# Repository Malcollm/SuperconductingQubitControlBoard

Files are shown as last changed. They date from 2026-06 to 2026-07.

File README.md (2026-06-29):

# Superconducting Qubit Control Board

Custom FPGA-based control board for generating microwave I/Q signals used to drive superconducting qubits.

## Project Overview

This project is a hardware and FPGA control system for producing shaped control signals for superconducting qubit experiments. The board uses an FPGA to generate digital waveform data, a high-speed DAC to convert that data into analog I/Q signals, and an RF stage to upconvert the signals to microwave frequencies.

## Main Components

- FPGA digital control and waveform generation
- High-speed DAC for analog I/Q output
- TRF372017 RF modulator / PLL / VCO stage
- SPI control for configurable RF components
- Low-pass filtering between DAC and RF stages
- On-board power regulation and decoupling
- RF output through a controlled-impedance path to SMA

## Design Goals

- Generate programmable I/Q waveforms
- Support microwave signal generation for qubit control
- Keep the design modular and testable
- Document RF layout, DAC interfacing, FPGA control, and signal integrity design

## Current Status

This project is currently in development. The main focus is schematic design, PCB layout, FPGA communication, and validating the signal chain from the FPGA to the RF output.

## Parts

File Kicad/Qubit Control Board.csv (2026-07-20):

Reference | Qty | Value | DNP | Exclude from BOM | Exclude from Board | Footprint | Datasheet
CBULK1,CBULK3,CBULK5,CBULK7,CIN1,CLDO3,CLDO4,CLDO5,CLDO6 | 9 | 10u |  |  |  | Capacitor_SMD:C_1206_3216Metric_Pad1.33x1.80mm_HandSolder
CBULK2,CBULK4,CBULK6,CBULK8 | 4 | 1u |  |  |  | Capacitor_SMD:C_0805_2012Metric_Pad1.18x1.45mm_HandSolder
CC1 | 1 | 47p |  |  |  | Capacitor_SMD:C_0603_1608Metric
CC2 | 1 | 22p |  |  |  | Capacitor_SMD:C_0603_1608Metric
CCDAC1,CCDAC2,CCIN1,CCIP1,CCQN1,CCQP1,CIN2,CRE1 | 8 | 100n |  |  |  | Capacitor_SMD:C_0603_1608Metric
CD1,CD2,CD3,CD4,CD5,CD6,CD7,CD8,CD9,CD10,CD28,CD29,CD30,CD32,CD34,CDC1,CSEN1,CSEN2,CSEN3 | 19 | 100n |  |  |  | Capacitor_SMD:C_0402_1005Metric
CD11,CD20,CD21,CD22,CD26 | 5 | 1u |  |  |  | Capacitor_SMD:C_0603_1608Metric
CD12,CD13,CD18,CD19,CD23,CD24,CD25 | 7 | 4.7p |  |  |  | Capacitor_SMD:C_0402_1005Metric
CD14,CD15,CD16,CD17,CD27 | 5 | 100p |  |  |  | Capacitor_SMD:C_0402_1005Metric
CD31,CD33,CD35,CD36 | 4 | 10n |  |  |  | Capacitor_SMD:C_0402_1005Metric
CIF1,CIF2,CQF1,CQF2 | 4 | 130p |  |  |  | Capacitor_SMD:C_0603_1608Metric
CLDO1,CLDO2 | 2 | 10u |  |  |  | Capacitor_SMD:C_0603_1608Metric
CLDOS1,CLDOS2,CLDOS3 | 3 | 470n |  |  |  | Capacitor_SMD:C_0402_1005Metric
CLF1 | 1 | 270p |  |  |  | Capacitor_SMD:C_0402_1005Metric
CLF2,CLF3 | 2 | 4.7n |  |  |  | Capacitor_SMD:C_0402_1005Metric
F1 | 1 |  |  |  |  | Fuse:Fuse_1206_3216Metric
FB1,FB2,FB3,FB4,FB5,FB6,FB7,FB8 | 8 | 1k @100MHz |  |  |  | Inductor_SMD:L_0603_1608Metric_Pad1.05x0.95mm_HandSolder
J1 | 1 | USB_C_Receptacle_PowerOnly_6P |  |  |  | Connector_USB:USB_C_Receptacle_GCT_USB4135-GF-A_6P_TopMnt_Horizontal | https://www.usb.org/sites/default/files/documents/usb_type-c.zip
J2 | 1 | CLK_Pins |  |  |  | Connector_PinHeader_1.00mm:PinHeader_1x02_P1.00mm_Vertical
J3 | 1 | Idata |  |  |  | Connector_PinHeader_1.00mm:PinHeader_1x11_P1.00mm_Vertical
J4 | 1 | Qdata |  |  |  | Connector_PinHeader_1.00mm:PinHeader_1x11_P1.00mm_Vertical
J5 | 1 | SPIdata |  |  |  | Connector_PinHeader_1.00mm:PinHeader_1x06_P1.00mm_Vertical
J6 | 1 | SMA |  |  |  | Connector_Coaxial:SMA_Molex_73251-1153_EdgeMount_Horizontal
RAP1,RDM1,RDM2,RDM3,RDM4,RDM5,RDM6,RDM7,RDM8 | 9 | 0R |  |  |  | Resistor_SMD:R_0603_1608Metric
RAP2,RAP3 | 2 | DNP |  |  |  | Resistor_SMD:R_0603_1608Metric
Rd1,Rd2 | 2 | 5.1k |  |  |  | Resistor_SMD:R_0603_1608Metric
RDIFF1,RDIFF4 | 2 | 49.9R |  |  |  | Resistor_SMD:R_0603_1608Metric
RDIFF2,RDIFF3 | 2 | 100R |  |  |  | Resistor_SMD:R_0402_1005Metric
RDIV1 | 1 | 1k |  |  |  | Resistor_SMD:R_0603_1608Metric
RDIV2 | 1 | 287R |  |  |  | Resistor_SMD:R_0603_1608Metric
RFS1,RPD1,RPD2,RPD3 | 4 | 10k |  |  |  | Resistor_SMD:R_0603_1608Metric
RID0,RID1,RID2,RID3,RID4,RID5,RID6,RID7,RID8,RID9,RQD0,RQD1,RQD2,RQD3,RQD4,RQD5,RQD6,RQD7,RQD8,RQD9,RT1,RT2,RTSPI1,RTSPI2,RTSPI3,RTSPI4,RTSPI5 | 27 | 33R |  |  |  | Resistor_SMD:R_0402_1005Metric
RINF1,RIPF1,RQNF1,RQPF1 | 4 | 33R |  |  |  | Resistor_SMD:R_0603_1608Metric
RLDOS1,RLDOS2 | 2 | 33.2k |  |  |  | Resistor_SMD:R_0603_1608Metric
RLDOS3 | 1 | 17.8k |  |  |  | Resistor_SMD:R_0603_1608Metric
RLF1,RLF2 | 2 | 1.5k |  |  |  | Resistor_SMD:R_0402_1005Metric
RLOAD1,RLOAD2,RLOAD3,RLOAD4 | 4 | 43.2R |  |  |  | Resistor_SMD:R_0603_1608Metric
U1,U3,U4 | 3 | LT3045xMSE |  |  |  | Package_SO:MSOP-12-1EP_3x4.039mm_P0.65mm_EP1.651x2.845mm | https://www.analog.com/media/en/technical-documentation/data-sheets/3045fa.pdf
U2 | 1 | TRF372017IRGZR |  |  |  | footprints789:RGZ48_5P6X5P6 | https://www.ti.com/lit/gpn/trf372017
U5 | 1 | SN65LVDS1DBV |  |  |  | Package_TO_SOT_SMD:SOT-23-5 | http://www.ti.com/lit/ds/symlink/sn65lvds1.pdf
U6 | 1 | AD9743BCPZ |  |  |  | footprints789:CP-72-1_ADI-M | https://www.analog.com/media/en/technical-documentation/data-sheets/AD9743_9745_9746_9747.pdf
Y2 | 1 | CVHD-950-100.000 |  |  |  | footprints789:OSCSC508P1420X914X530-4N

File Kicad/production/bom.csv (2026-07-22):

Designator | Footprint | Quantity | Value | LCSC Part #
CBULK1, CBULK3, CBULK5, CBULK7, CIN1, CLDO3, CLDO4, CLDO5, CLDO6 | 1206 | 9 | 10u
CBULK2, CBULK4, CBULK6, CBULK8 | 0805 | 4 | 1u
CC1 | 0603 | 1 | 47p
CC2 | 0603 | 1 | 22p
CCDAC1, CCDAC2, CCIN1, CCIP1, CCQN1, CCQP1, CIN2, CRE1 | 0603 | 8 | 100n
CD1, CD10, CD2, CD28, CD29, CD3, CD30, CD32, CD34, CD4, CD5, CD6, CD7, CD8, CD9, CDC1, CSEN1, CSEN2, CSEN3 | 0402 | 19 | 100n
CD11, CD20, CD21, CD22, CD26 | 0603 | 5 | 1u
CD12, CD13, CD18, CD19, CD23, CD24, CD25 | 0402 | 7 | 4.7p
CD14, CD15, CD16, CD17, CD27 | 0402 | 5 | 100p
CD31, CD33, CD35, CD36 | 0402 | 4 | 10n
CIF1, CIF2, CQF1, CQF2 | 0603 | 4 | 130p
CLDO1, CLDO2 | 0603 | 2 | 10u
CLDOS1, CLDOS2, CLDOS3 | 0402 | 3 | 470n
CLF1 | 0402 | 1 | 270p
CLF2, CLF3 | 0402 | 2 | 4.7n
F1 | 1206 | 1 | ~
FB1, FB2, FB3, FB4, FB5, FB6, FB7, FB8 | 0603 | 8 | 1k @100MHz
J1 | USB_C_Receptacle_GCT_USB4135-GF-A_6P_TopMnt_Horizontal | 1 | USB_C_Receptacle_PowerOnly_6P
J2 | PinHeader_1x02_P1.00mm_Vertical | 1 | CLK_Pins
J3 | PinHeader_1x11_P1.00mm_Vertical | 1 | Idata
J4 | PinHeader_1x11_P1.00mm_Vertical | 1 | Qdata
J5 | PinHeader_1x06_P1.00mm_Vertical | 1 | SPIdata
J6 | SMA_Molex_73251-1153_EdgeMount_Horizontal | 1 | SMA
RAP1, RDM1, RDM2, RDM3, RDM4, RDM5, RDM6, RDM7, RDM8 | 0603 | 9 | 0R
RAP2, RAP3 | 0603 | 2 | DNP
RD1, RD2 | 0603 | 2 | 5.1k
RDIFF1, RDIFF4 | 0603 | 2 | 49.9R
RDIFF2, RDIFF3 | 0402 | 2 | 100R
RDIV1 | 0603 | 1 | 1k
RDIV2 | 0603 | 1 | 287R
RFS1, RPD1, RPD2, RPD3 | 0603 | 4 | 10k
RID0, RID1, RID2, RID3, RID4, RID5, RID6, RID7, RID8, RID9, RQD0, RQD1, RQD2, RQD3, RQD4, RQD5, RQD6, RQD7, RQD8, RQD9, RT1, RT2, RTSPI1, RTSPI2, RTSPI3, RTSPI4, RTSPI5 | 0402 | 27 | 33R
RINF1, RIPF1, RQNF1, RQPF1 | 0603 | 4 | 33R
RLDOS1, RLDOS2 | 0603 | 2 | 33.2k
RLDOS3 | 0603 | 1 | 17.8k
RLF1, RLF2 | 0402 | 2 | 1.5k
RLOAD1, RLOAD2, RLOAD3, RLOAD4 | 0603 | 4 | 43.2R
U1, U3, U4 | MSOP-12-1EP_3x4.039mm_P0.65mm_EP1.651x2.845mm | 3 | LT3045xMSE
U2 | RGZ48_5P6X5P6 | 1 | TRF372017IRGZR
U5 | SOT-23-5 | 1 | SN65LVDS1DBV
U6 | CP-72-1_ADI-M | 1 | AD9743BCPZ
Y2 | OSCSC508P1420X914X530-4N | 1 | CVHD-950-100.000

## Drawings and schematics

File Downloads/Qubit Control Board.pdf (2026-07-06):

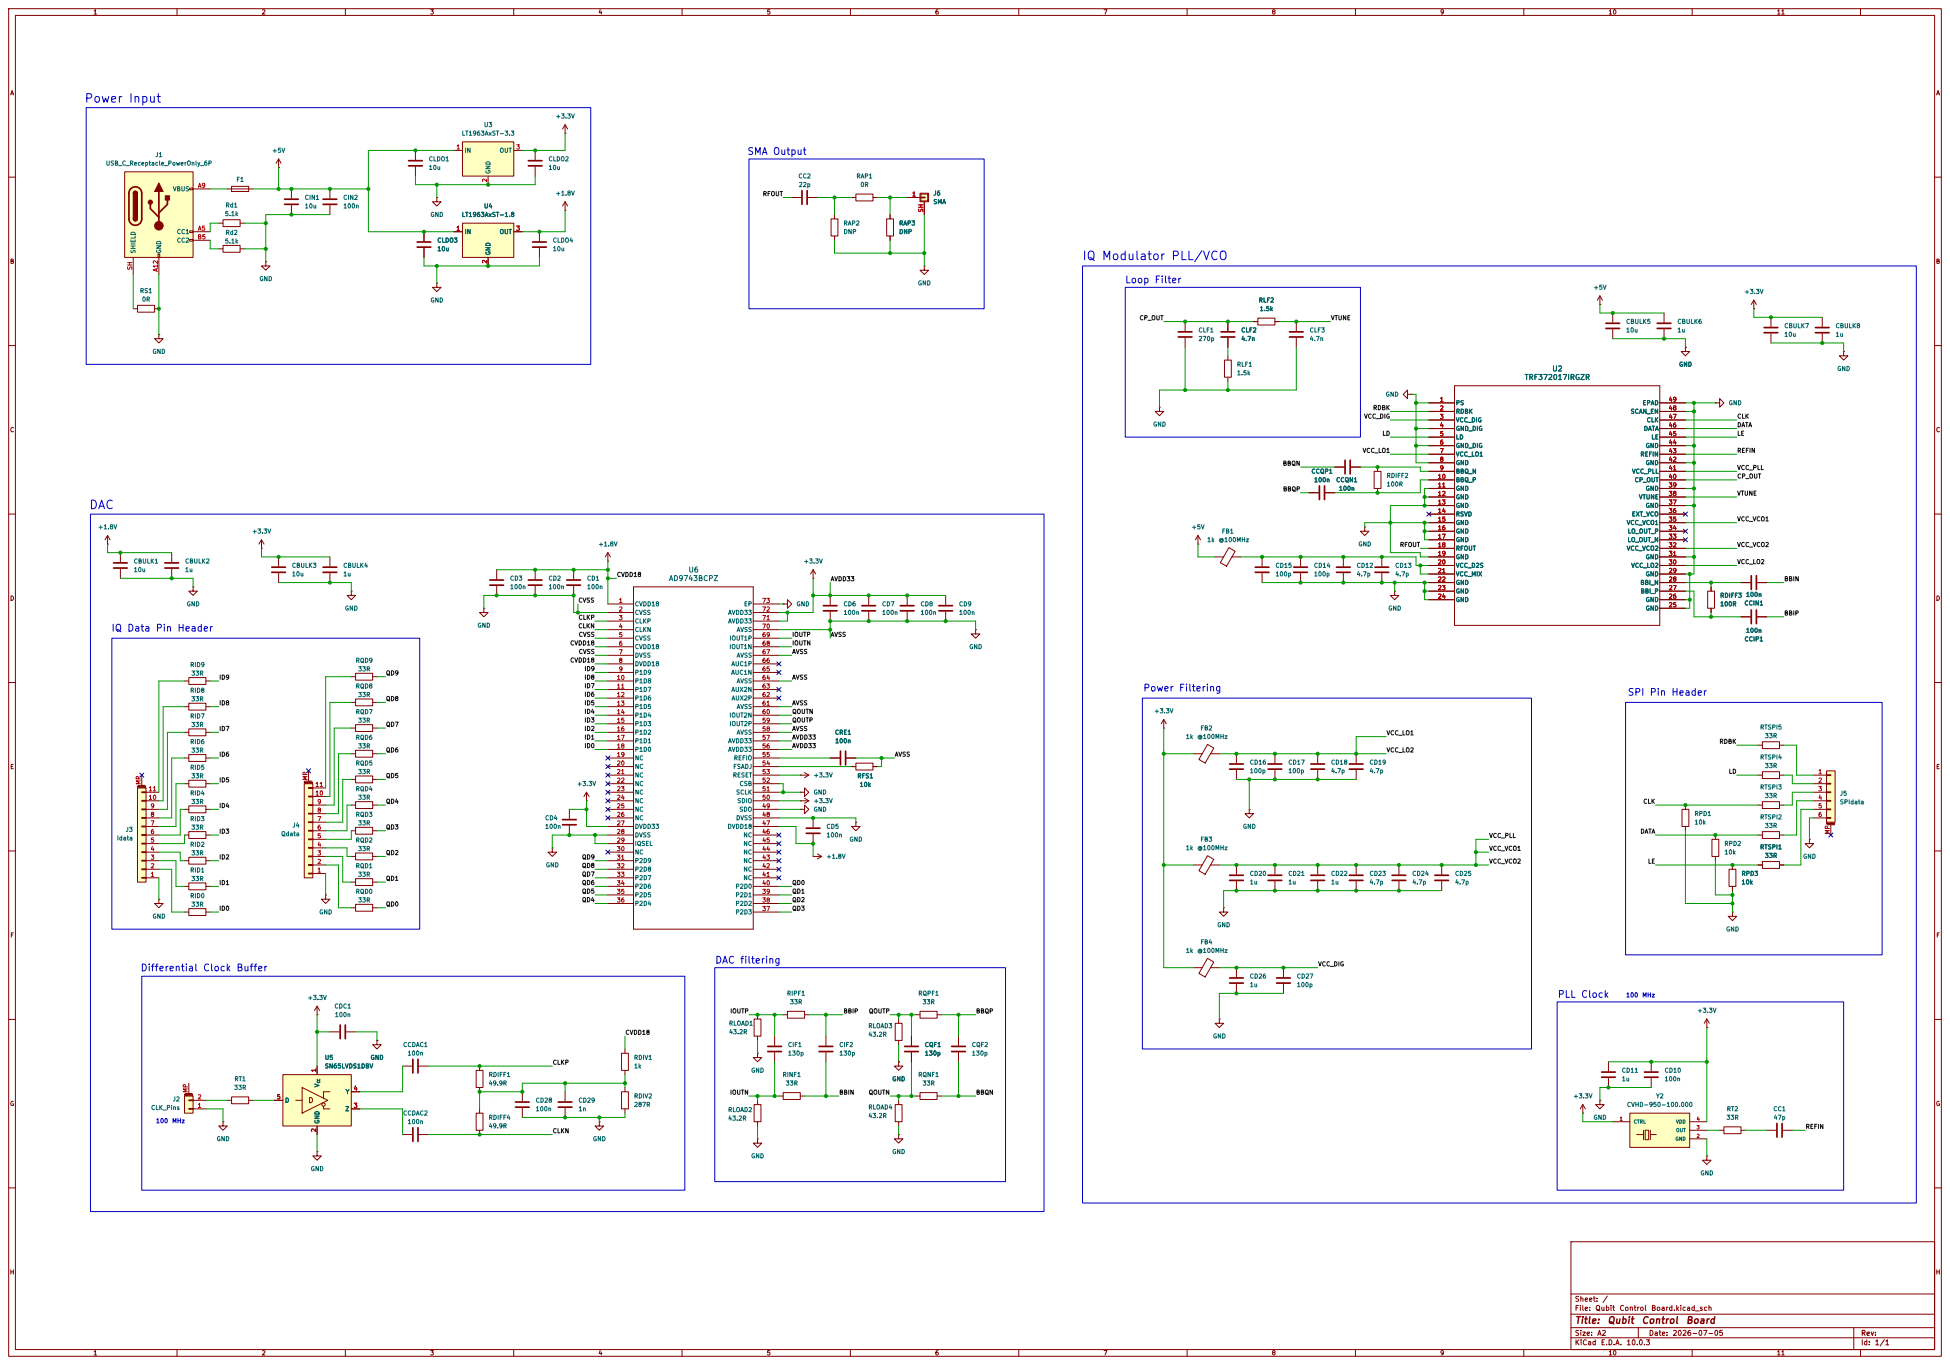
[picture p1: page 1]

IQ Data Pin Header

SPI Pin Header Power Filtering

100 MHz Differential Clock Buffer

Sheet: /
File: Qubit Control Board.kicad_sch
Title: Qubit Control Board

Size: A2 | Rev:
KiCad E.D.A. 10.0.3 | Id: 1/1

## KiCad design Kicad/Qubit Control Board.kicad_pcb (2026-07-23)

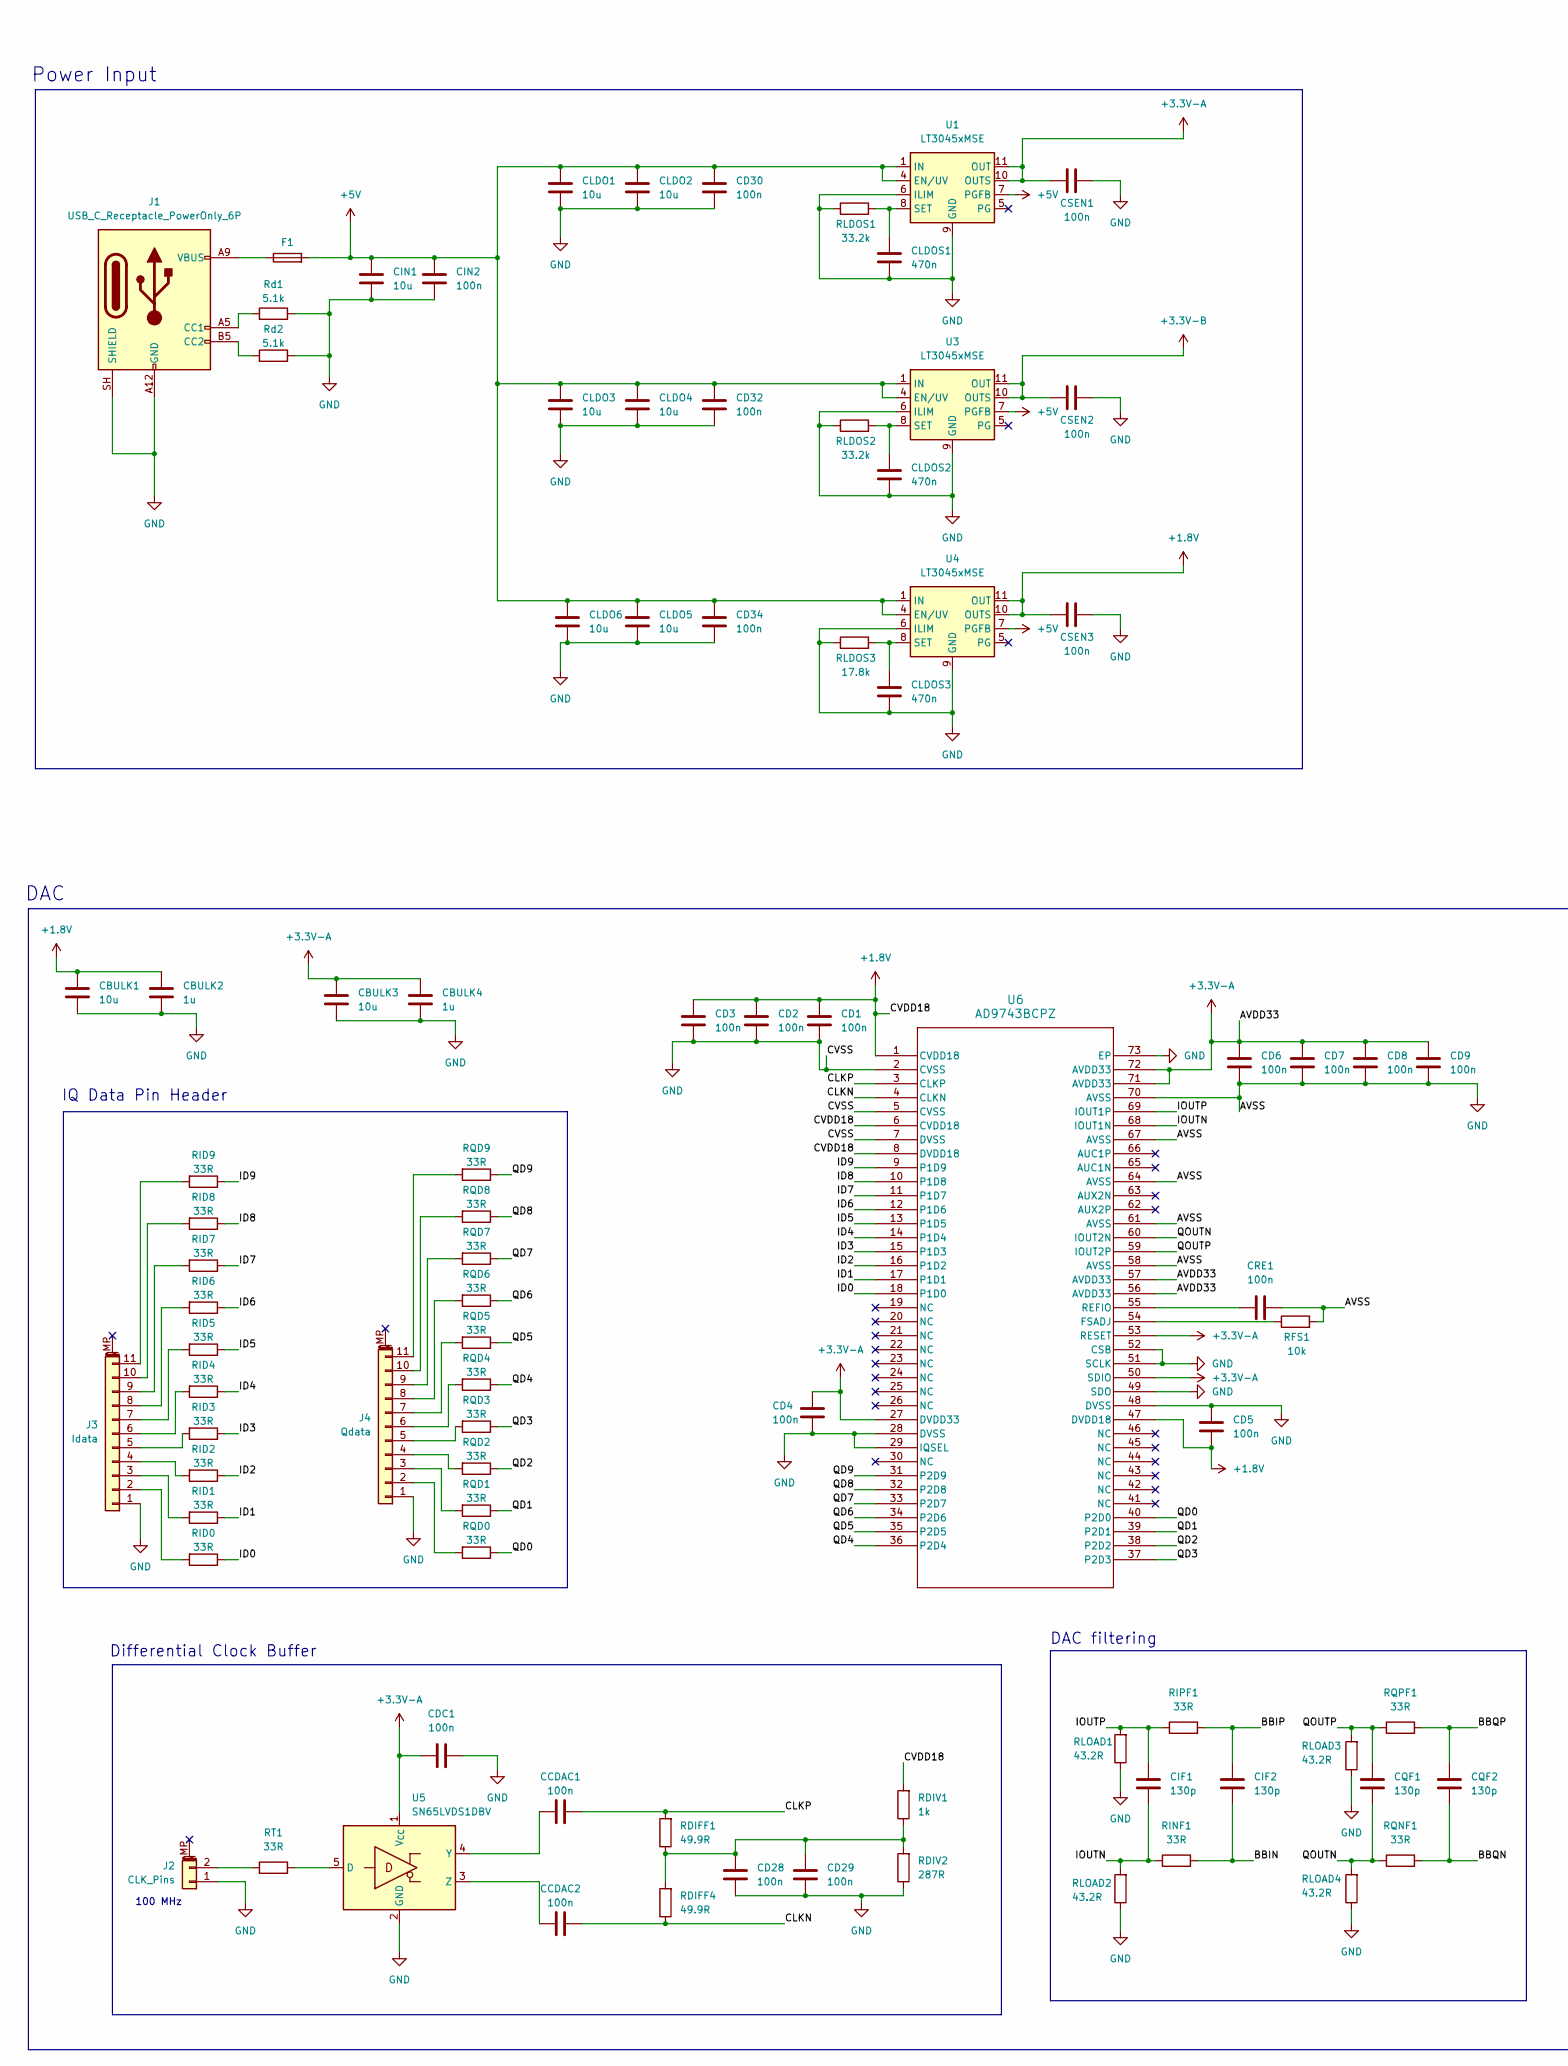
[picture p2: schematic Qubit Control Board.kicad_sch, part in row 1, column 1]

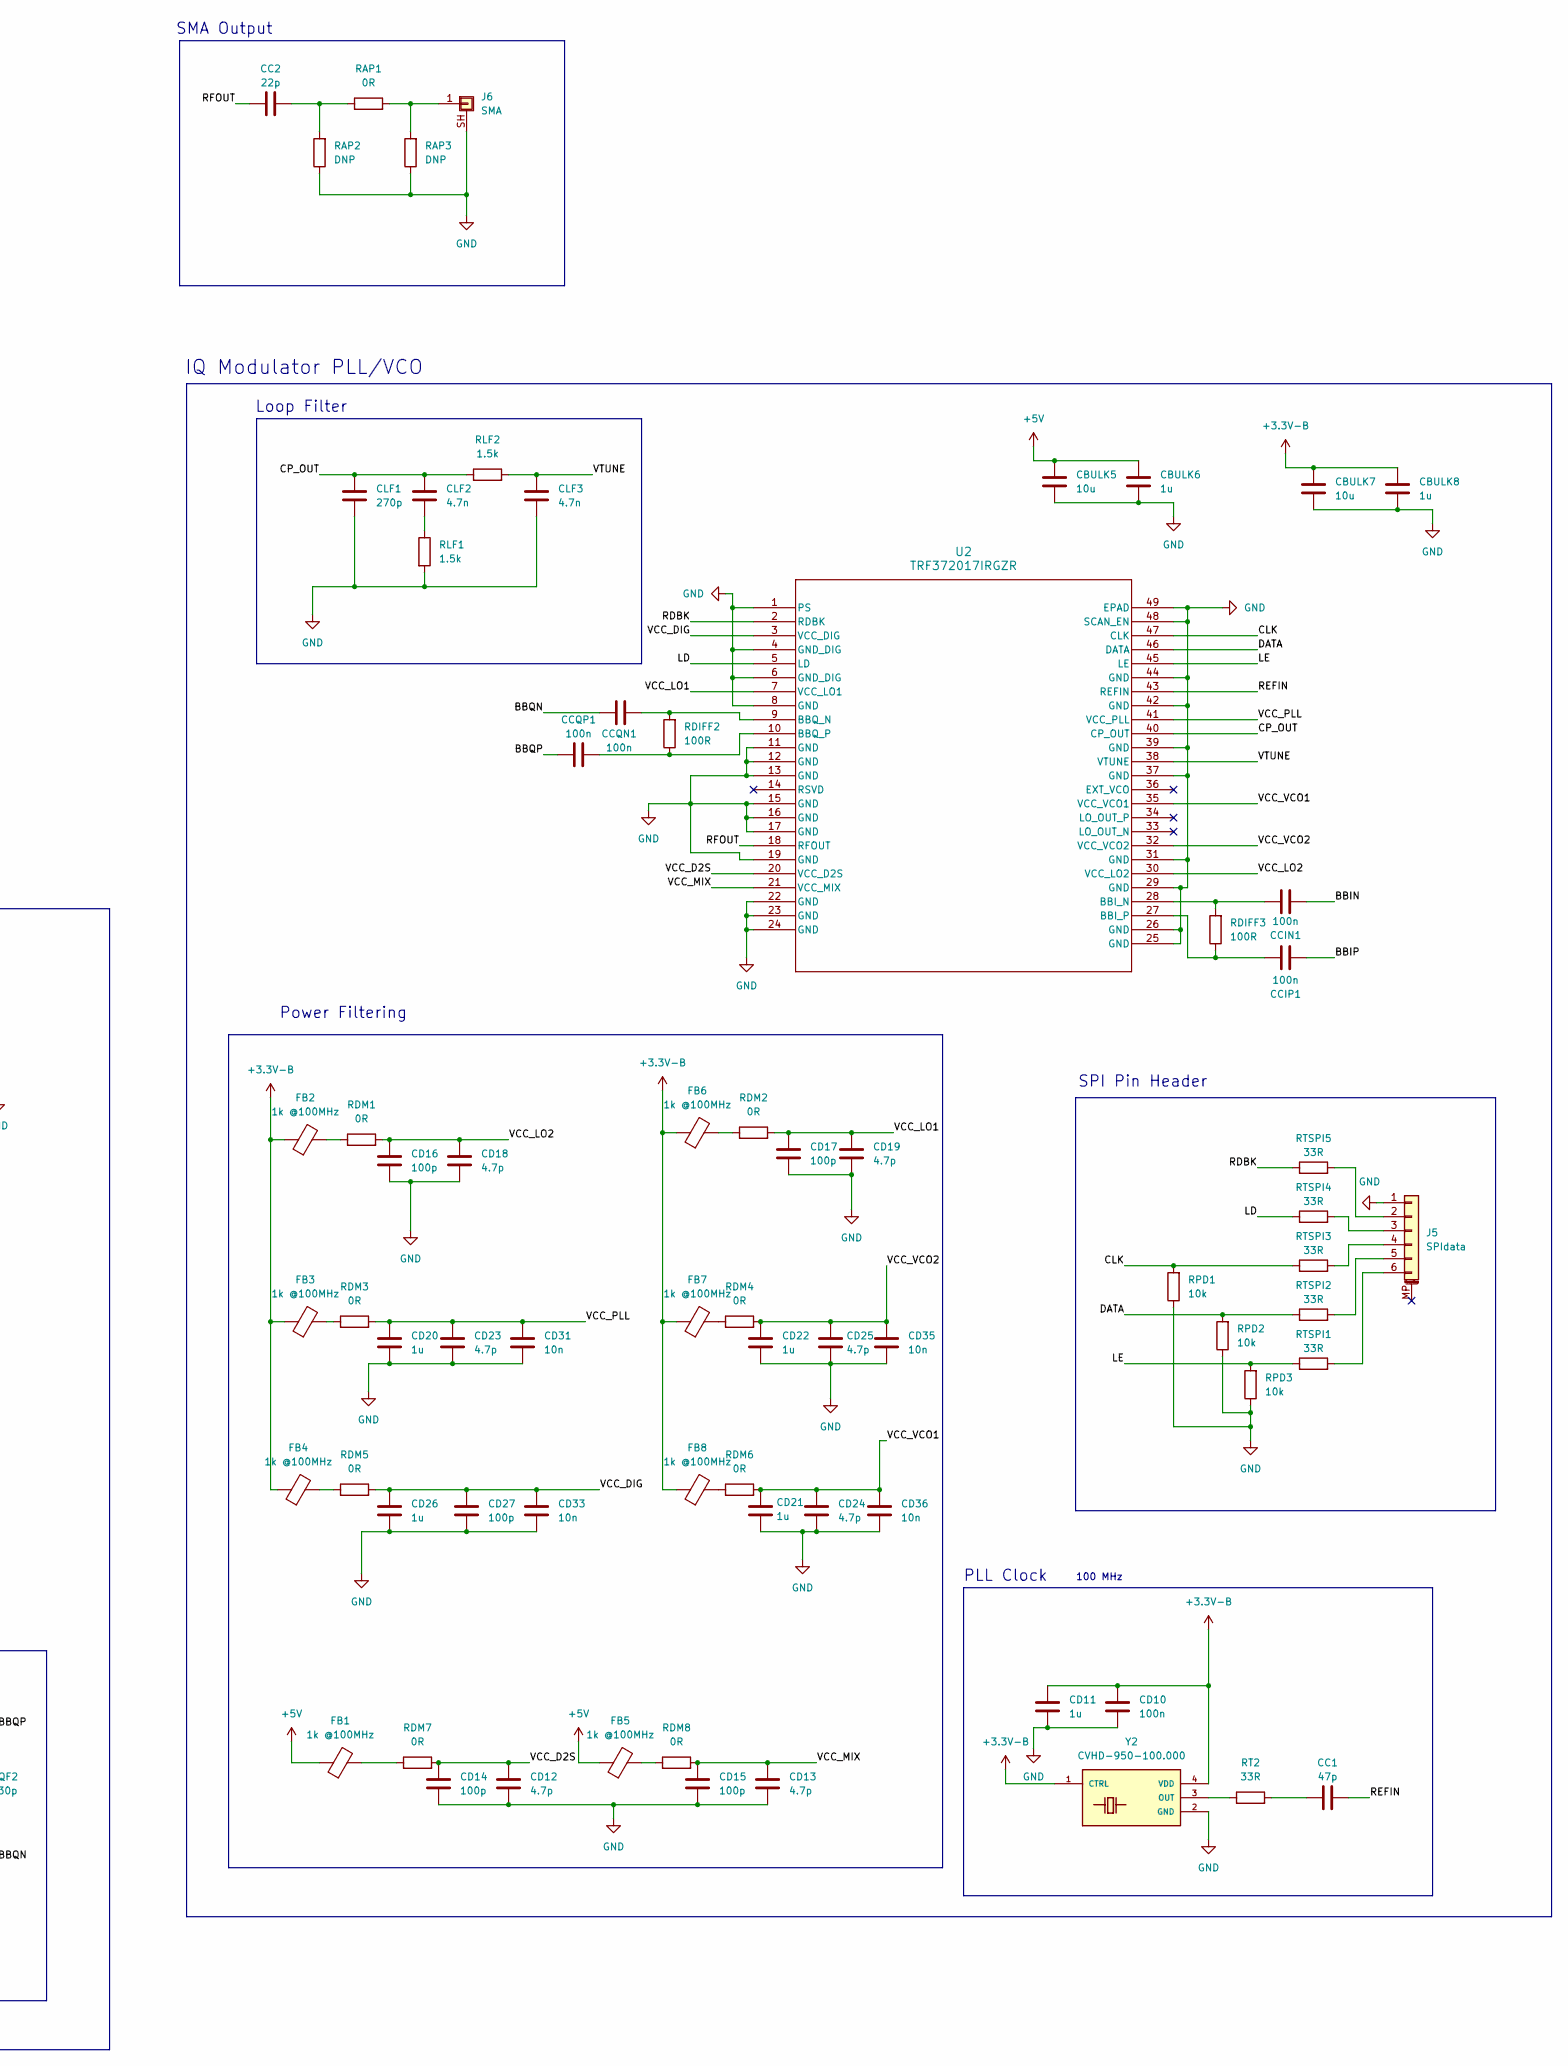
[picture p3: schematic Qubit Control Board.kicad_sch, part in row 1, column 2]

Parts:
CBULK1, CBULK3, CBULK5, CBULK7: 10u; C_1206_3216Metric_Pad1.33x1.80mm_HandSolder
CBULK2, CBULK4, CBULK6, CBULK8: 1u; C_0805_2012Metric_Pad1.18x1.45mm_HandSolder
CC1: 47p; C_0603_1608Metric
CC2: 22p; C_0603_1608Metric
CCDAC1, CCDAC2: 100n; C_0603_1608Metric
CCIN1: 100n; C_0603_1608Metric
CCIP1: 100n; C_0603_1608Metric
CCQN1: 100n; C_0603_1608Metric
CCQP1: 100n; C_0603_1608Metric
CD1, CD2, CD3, CD4, CD5, CD6, CD7, CD8, CD9, CD10, CD28, CD29, CD30, CD32, CD34: 100n; C_0402_1005Metric
CD11, CD20, CD21, CD22, CD26: 1u; C_0603_1608Metric
CD12, CD13, CD18, CD19, CD23, CD24, CD25: 4.7p; C_0402_1005Metric
CD14, CD15, CD16, CD17, CD27: 100p; C_0402_1005Metric
CD31, CD33, CD35, CD36: 10n; C_0402_1005Metric
CDC1: 100n; C_0402_1005Metric
CIF1, CIF2: 130p; C_0603_1608Metric
CIN1: 10u; C_1206_3216Metric_Pad1.33x1.80mm_HandSolder
CIN2: 100n; C_0603_1608Metric
CLDO1, CLDO2: 10u; C_0603_1608Metric
CLDO3, CLDO4, CLDO5, CLDO6: 10u; C_1206_3216Metric_Pad1.33x1.80mm_HandSolder
CLDOS1, CLDOS2, CLDOS3: 470n; C_0402_1005Metric
CLF1: 270p; C_0402_1005Metric
CLF2, CLF3: 4.7n; C_0402_1005Metric
CQF1, CQF2: 130p; C_0603_1608Metric
CRE1: 100n; C_0603_1608Metric
CSEN1, CSEN2, CSEN3: 100n; C_0402_1005Metric
F1: Fuse_1206_3216Metric
FB1, FB2, FB3, FB4, FB5, FB6, FB7, FB8: 1k @100MHz; L_0603_1608Metric_Pad1.05x0.95mm_HandSolder
J1: USB_C_Receptacle_PowerOnly_6P; USB_C_Receptacle_GCT_USB4135-GF-A_6P_TopMnt_Horizontal
J2: CLK_Pins; PinHeader_1x02_P1.00mm_Vertical
J3: Idata; PinHeader_1x11_P1.00mm_Vertical
J4: Qdata; PinHeader_1x11_P1.00mm_Vertical
J5: SPIdata; PinHeader_1x06_P1.00mm_Vertical
J6: SMA; SMA_Molex_73251-1153_EdgeMount_Horizontal
RAP1: 0R; R_0603_1608Metric
RAP2, RAP3: DNP; R_0603_1608Metric
RDIFF1, RDIFF4: 49.9R; R_0603_1608Metric
RDIFF2, RDIFF3: 100R; R_0402_1005Metric
RDIV1: 1k; R_0603_1608Metric
RDIV2: 287R; R_0603_1608Metric
RDM1, RDM2, RDM3, RDM4, RDM5, RDM6, RDM7, RDM8: 0R; R_0603_1608Metric
RFS1: 10k; R_0603_1608Metric
RID0, RID1, RID2, RID3, RID4, RID5, RID6, RID7, RID8, RID9: 33R; R_0402_1005Metric
RINF1: 33R; R_0603_1608Metric
RIPF1: 33R; R_0603_1608Metric
RLDOS1, RLDOS2: 33.2k; R_0603_1608Metric
RLDOS3: 17.8k; R_0603_1608Metric
RLF1, RLF2: 1.5k; R_0402_1005Metric
RLOAD1, RLOAD2, RLOAD3, RLOAD4: 43.2R; R_0603_1608Metric
RPD1, RPD2, RPD3: 10k; R_0603_1608Metric
RQD0, RQD1, RQD2, RQD3, RQD4, RQD5, RQD6, RQD7, RQD8, RQD9: 33R; R_0402_1005Metric
RQNF1: 33R; R_0603_1608Metric
RQPF1: 33R; R_0603_1608Metric
RT1, RT2: 33R; R_0402_1005Metric
RTSPI1, RTSPI2, RTSPI3, RTSPI4, RTSPI5: 33R; R_0402_1005Metric
Rd1, Rd2: 5.1k; R_0603_1608Metric
U1, U3, U4: LT3045xMSE; MSOP-12-1EP_3x4.039mm_P0.65mm_EP1.651x2.845mm
U2: TRF372017IRGZR; RGZ48_5P6X5P6
U5: SN65LVDS1DBV; SOT-23-5
U6: AD9743BCPZ; CP-72-1_ADI-M
Y2: CVHD-950-100.000; OSCSC508P1420X914X530-4N

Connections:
+1.8V: CBULK1.1, CBULK2.1, CD1.2, CD2.2, CD3.2, CD5.1, CSEN3.2, RDIV1.2, U4.10 (OUTS), U4.11 (OUT), U4.12 (OUT), U6.1 (CVDD18), U6.6 (CVDD18), U6.8 (DVDD18), U6.47 (DVDD18)
+3.3V-A: CBULK3.1, CBULK4.1, CD4.2, CD6.2, CD7.2, CD8.2, CD9.2, CDC1.1, CSEN1.2, U1.10 (OUTS), U1.11 (OUT), U1.12 (OUT), U5.1 (V_{CC}), U6.27 (DVDD33), U6.50 (SDIO), U6.53 (RESET), U6.56 (AVDD33), U6.57 (AVDD33), U6.71 (AVDD33), U6.72 (AVDD33)
+3.3V-B: CBULK7.1, CBULK8.1, CD10.2, CD11.2, CSEN2.2, FB2.1, FB3.1, FB4.1, FB6.1, FB7.1, FB8.1, U3.10 (OUTS), U3.11 (OUT), U3.12 (OUT), Y2.1 (CTRL), Y2.4 (VDD)
+5V: CBULK5.1, CBULK6.1, CD30.2, CD32.2, CD34.2, CIN1.1, CIN2.1, CLDO1.1, CLDO2.1, CLDO3.1, CLDO4.1, CLDO5.1, CLDO6.1, F1.2, FB1.1, FB5.1, U1.1 (IN), U1.2 (IN), U1.3 (IN), U1.4 (EN/UV), U1.7 (PGFB), U3.1 (IN), U3.2 (IN), U3.3 (IN), U3.4 (EN/UV), U3.7 (PGFB), U4.1 (IN), U4.2 (IN), U4.3 (IN), U4.4 (EN/UV), U4.7 (PGFB)
/BBIN: CCIN1.1, CIF2.2, RINF1.2
/BBIP: CCIP1.1, CIF2.1, RIPF1.2
/BBQN: CCQN1.1, CQF2.2, RQNF1.2
/BBQP: CCQP1.1, CQF2.1, RQPF1.2
/CLK: RPD1.2, RTSPI3.1, U2.47 (CLK)
/CLKN: CCDAC2.2, RDIFF4.1, U6.4 (CLKN)
/CLKP: CCDAC1.2, RDIFF1.2, U6.3 (CLKP)
/CP_OUT: CLF1.1, CLF2.1, RLF2.1, U2.40 (CP_OUT)
/DATA: RPD2.2, RTSPI2.1, U2.46 (DATA)
/ID0: RID0.1, U6.18 (P1D0)
/ID1: RID1.1, U6.17 (P1D1)
/ID2: RID2.1, U6.16 (P1D2)
/ID3: RID3.1, U6.15 (P1D3)
/ID4: RID4.1, U6.14 (P1D4)
/ID5: RID5.1, U6.13 (P1D5)
/ID6: RID6.1, U6.12 (P1D6)
/ID7: RID7.1, U6.11 (P1D7)
/ID8: RID8.1, U6.10 (P1D8)
/ID9: RID9.1, U6.9 (P1D9)
/IOUTN: CIF1.2, RINF1.1, RLOAD2.2, U6.68 (IOUT1N)
/IOUTP: CIF1.1, RIPF1.1, RLOAD1.2, U6.69 (IOUT1P)
/LD: RTSPI4.1, U2.5 (LD)
/LE: RPD3.2, RTSPI1.1, U2.45 (LE)
/QD0: RQD0.1, U6.40 (P2D0)
/QD1: RQD1.1, U6.39 (P2D1)
/QD2: RQD2.1, U6.38 (P2D2)
/QD3: RQD3.1, U6.37 (P2D3)
/QD4: RQD4.1, U6.36 (P2D4)
/QD5: RQD5.1, U6.35 (P2D5)
/QD6: RQD6.1, U6.34 (P2D6)
/QD7: RQD7.1, U6.33 (P2D7)
/QD8: RQD8.1, U6.32 (P2D8)
/QD9: RQD9.1, U6.31 (P2D9)
/QOUTN: CQF1.2, RLOAD4.2, RQNF1.1, U6.60 (IOUT2N)
/QOUTP: CQF1.1, RLOAD3.2, RQPF1.1, U6.59 (IOUT2P)
/RDBK: RTSPI5.1, U2.2 (RDBK)
/REFIN: CC1.2, U2.43 (REFIN)
/RFOUT: CC2.1, U2.18 (RFOUT)
/VCC_D2S: CD12.2, CD14.2, RDM7.2, U2.20 (VCC_D2S)
/VCC_DIG: CD26.2, CD27.2, CD33.2, RDM5.2, U2.3 (VCC_DIG)
/VCC_LO1: CD17.2, CD19.2, RDM2.2, U2.7 (VCC_LO1)
/VCC_LO2: CD16.2, CD18.2, RDM1.2, U2.30 (VCC_LO2)
/VCC_MIX: CD13.2, CD15.2, RDM8.2, U2.21 (VCC_MIX)
/VCC_PLL: CD20.2, CD23.2, CD31.2, RDM3.2, U2.41 (VCC_PLL)
/VCC_VCO1: CD21.2, CD24.2, CD36.2, RDM6.2, U2.35 (VCC_VCO1)
/VCC_VCO2: CD22.2, CD25.2, CD35.2, RDM4.2, U2.32 (VCC_VCO2)
/VTUNE: CLF3.1, RLF2.2, U2.38 (VTUNE)
GND: CBULK1.2, CBULK2.2, CBULK3.2, CBULK4.2, CBULK5.2, CBULK6.2, CBULK7.2, CBULK8.2, CD1.1, CD2.1, CD3.1, CD4.1, CD5.2, CD6.1, CD7.1, CD8.1, CD9.1, CD10.1, CD11.1, CD12.1, CD13.1, CD14.1, CD15.1, CD16.1, CD17.1, CD18.1, CD19.1, CD20.1, CD21.1, CD22.1, CD23.1, CD24.1, CD25.1, CD26.1, CD27.1, CD28.1, CD29.1, CD30.1, CD31.1, CD32.1, CD33.1, CD34.1, CD35.1, CD36.1, CDC1.2, CIN1.2, CIN2.2, CLDO1.2, CLDO2.2, CLDO3.2, CLDO4.2, CLDO5.2, CLDO6.2, CLDOS1.1, CLDOS2.1, CLDOS3.1, CLF1.2, CLF3.2, CRE1.1, CSEN1.1, CSEN2.1, CSEN3.1, J1.A12 (GND), J1.B12 (GND), J1.SH (SHIELD), J2.1, J3.1, J4.1, J5.1, J6.SH (Shield), RAP2.1, RAP3.1, RDIV2.1, RFS1.2, RLDOS1.1, RLDOS2.1, RLDOS3.1, RLF1.2, RLOAD1.1, RLOAD2.1, RLOAD3.1, RLOAD4.1, RPD1.1, RPD2.1, RPD3.1, Rd1.2, Rd2.2, U1.6 (ILIM), U1.9 (GND), U1.13 (GND), U2.1 (PS), U2.4 (GND_DIG), U2.6 (GND_DIG), U2.8 (GND), U2.11 (GND), U2.12 (GND), U2.13 (GND), U2.15 (GND), U2.16 (GND), U2.17 (GND), U2.19 (GND), U2.22 (GND), U2.23 (GND), U2.24 (GND), U2.25 (GND), U2.26 (GND), U2.29 (GND), U2.31 (GND), U2.37 (GND), U2.39 (GND), U2.42 (GND), U2.44 (GND), U2.48 (SCAN_EN), U2.49 (EPAD), U3.6 (ILIM), U3.9 (GND), U3.13 (GND), U4.6 (ILIM), U4.9 (GND), U4.13 (GND), U5.2 (GND), U6.2 (CVSS), U6.5 (CVSS), U6.7 (DVSS), U6.28 (DVSS), U6.29 (IQSEL), U6.48 (DVSS), U6.49 (SDO), U6.51 (SCLK), U6.52 (CSB), U6.58 (AVSS), U6.61 (AVSS), U6.64 (AVSS), U6.67 (AVSS), U6.70 (AVSS), U6.73 (EP), Y2.2 (GND)
unnamed: CC1.1, RT2.2
unnamed: CC2.2, RAP1.1, RAP2.2
unnamed: CD28.2, CD29.2, RDIFF1.1, RDIFF4.2, RDIV1.1, RDIV2.2
unnamed: CLF2.2, RLF1.1
unnamed: F1.1, J1.A9 (VBUS), J1.B9 (VBUS)
unnamed: FB1.2, RDM7.1
unnamed: FB2.2, RDM1.1
unnamed: FB3.2, RDM3.1
unnamed: FB4.2, RDM5.1
unnamed: FB5.2, RDM8.1
unnamed: FB6.2, RDM2.1
unnamed: FB7.2, RDM4.1
unnamed: FB8.2, RDM6.1
unnamed: J1.A5 (CC1), Rd1.1
unnamed: J1.B5 (CC2), Rd2.1
unnamed: J2.2, RT1.1
unnamed: J3.2, RID0.2
unnamed: J3.3, RID1.2
unnamed: J3.4, RID2.2
unnamed: J3.5, RID3.2
unnamed: J3.6, RID4.2
unnamed: J3.7, RID5.2
unnamed: J3.8, RID6.2
unnamed: J3.9, RID7.2
unnamed: J3.10, RID8.2
unnamed: J3.11, RID9.2
unnamed: J4.2, RQD0.2
unnamed: J4.3, RQD1.2
unnamed: J4.4, RQD2.2
unnamed: J4.5, RQD3.2
unnamed: J4.6, RQD4.2
unnamed: J4.7, RQD5.2
unnamed: J4.8, RQD6.2
unnamed: J4.9, RQD7.2
unnamed: J4.10, RQD8.2
unnamed: J4.11, RQD9.2
unnamed: J5.2, RTSPI5.2
unnamed: J5.3, RTSPI4.2
unnamed: J5.4, RTSPI3.2
unnamed: J5.5, RTSPI2.2
unnamed: J5.6, RTSPI1.2
unnamed: J6.1 (Pin_1_1), RAP1.2, RAP3.2
unnamed: CLDOS1.2, RLDOS1.2, U1.8 (SET)
unnamed: CCIN1.2, RDIFF3.2, U2.28 (BBI_N)
unnamed: CCIP1.2, RDIFF3.1, U2.27 (BBI_P)
unnamed: CCQN1.2, RDIFF2.2, U2.9 (BBQ_N)
unnamed: CCQP1.2, RDIFF2.1, U2.10 (BBQ_P)
unnamed: CLDOS2.2, RLDOS2.2, U3.8 (SET)
unnamed: CLDOS3.2, RLDOS3.2, U4.8 (SET)
unnamed: RT1.2, U5.5 (D)
unnamed: CCDAC1.1, U5.4 (Y)
unnamed: CCDAC2.1, U5.3 (Z)
unnamed: RFS1.1, U6.54 (FSADJ)
unnamed: CRE1.2, U6.55 (REFIO)
unnamed: RT2.1, Y2.3 (OUT)

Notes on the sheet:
SMA Output
100 MHz
SPI Pin Header
Power Filtering
DAC filtering
Loop Filter
IQ Data Pin Header
DAC
IQ Modulator PLL/VCO
Differential Clock Buffer
Power Input
PLL Clock

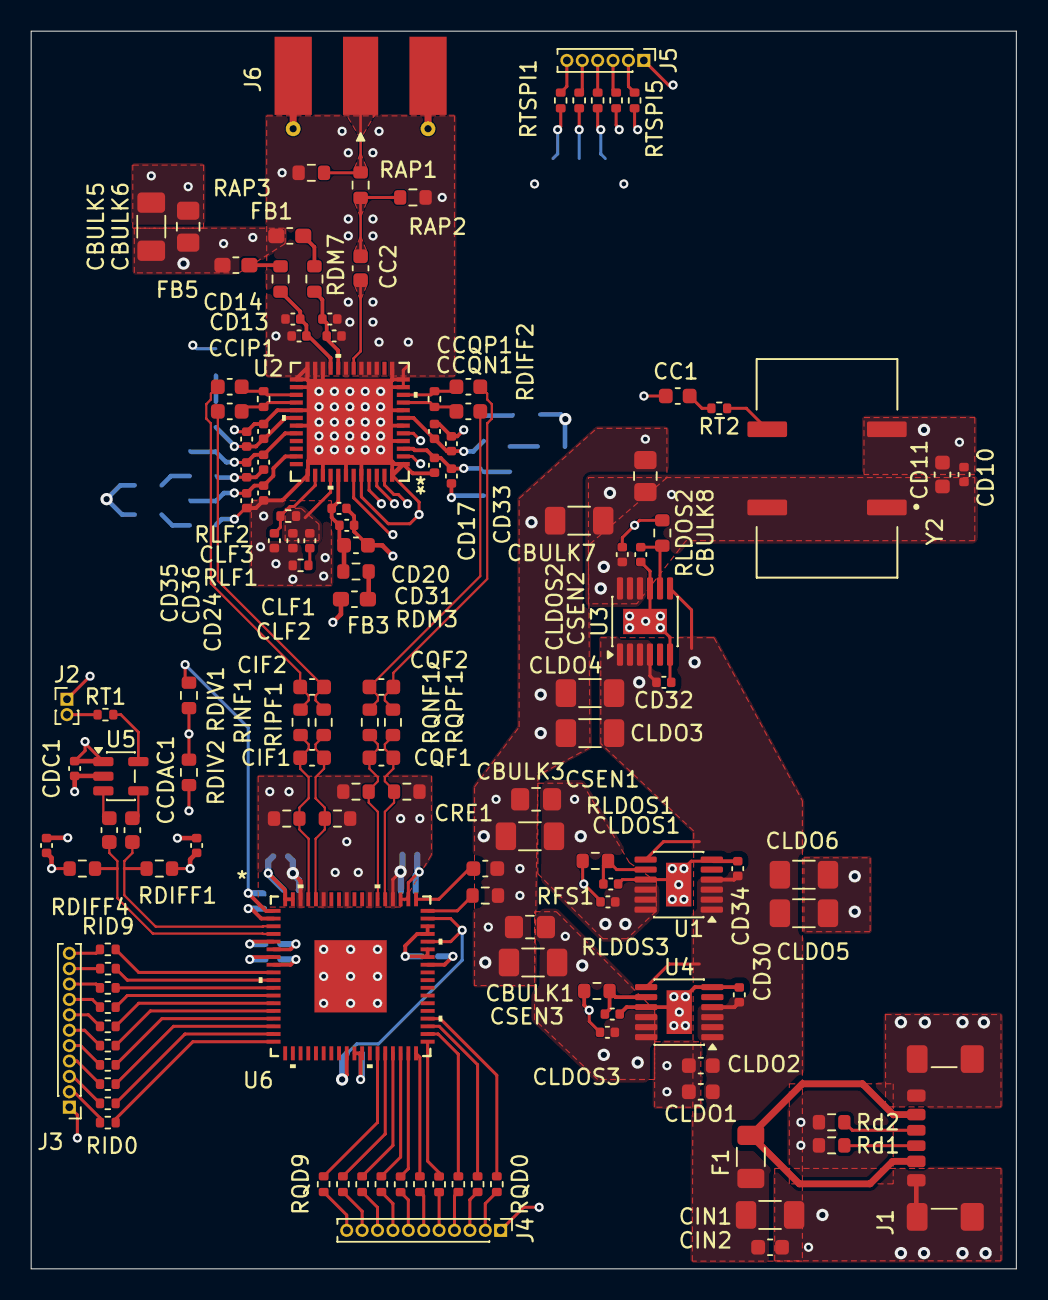
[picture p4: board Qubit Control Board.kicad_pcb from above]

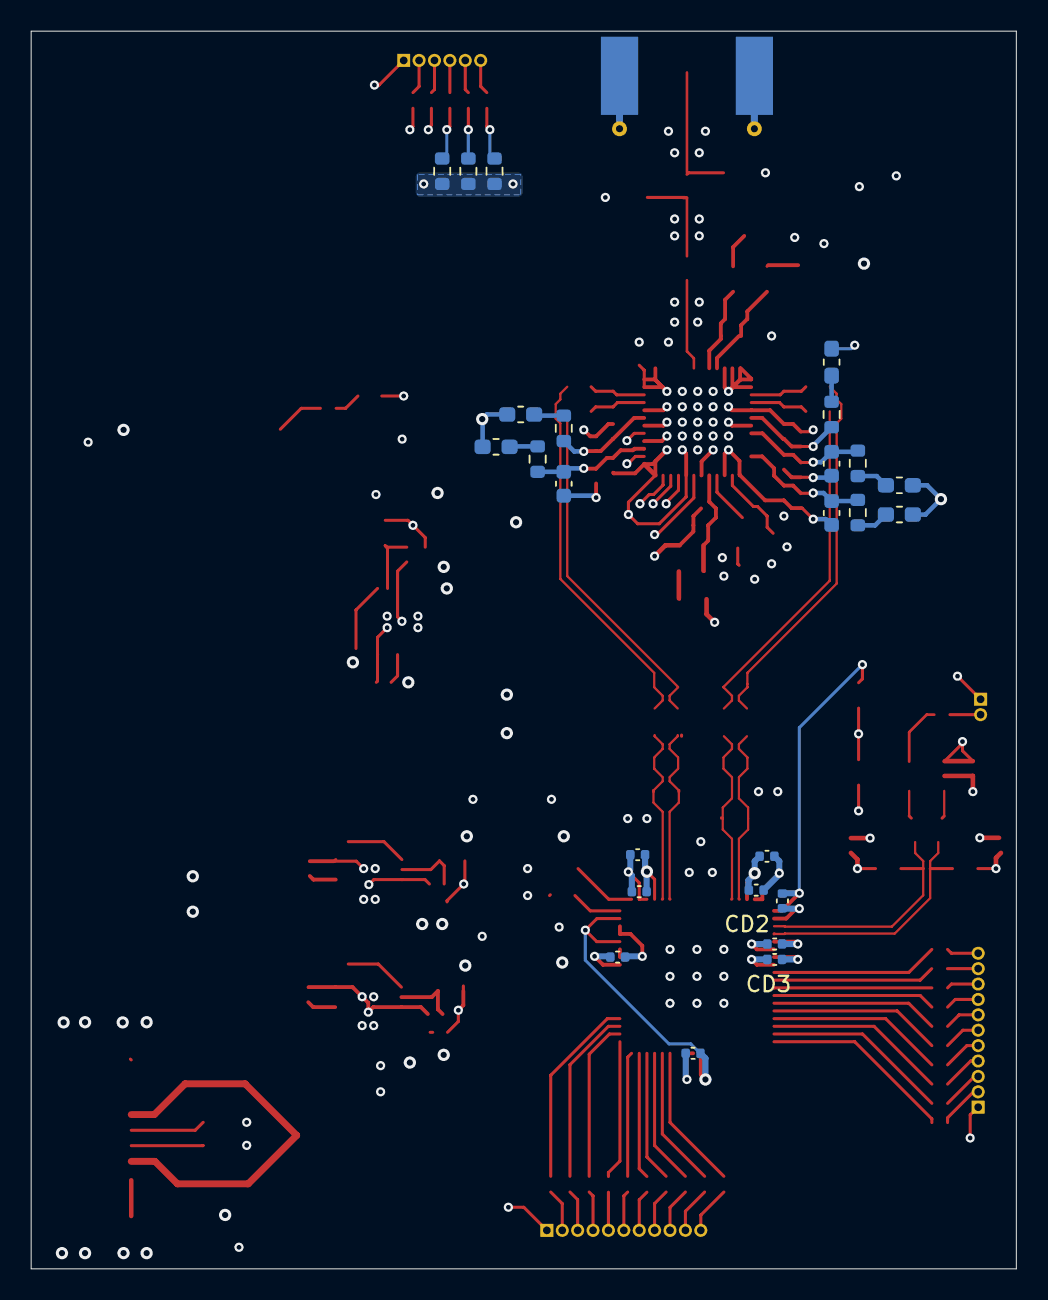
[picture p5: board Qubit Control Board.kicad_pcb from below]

Board: 6 copper layers, 64.0 x 80.4 mm, 160 parts (25 on the bottom side), 107 nets.

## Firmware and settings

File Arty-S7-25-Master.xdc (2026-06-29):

## This file is a general .xdc for the Arty S7-25 Rev. E
## To use it in a project:
## - uncomment the lines corresponding to used pins
## - rename the used ports (in each line, after get_ports) according to the top level signal names in the project

## Clock Signals
#set_property -dict { PACKAGE_PIN F14   IOSTANDARD LVCMOS33 } [get_ports { CLK12MHZ }]; #IO_L13P_T2_MRCC_15 Sch=uclk
#create_clock -add -name sys_clk_pin -period 83.333 -waveform {0 41.667} [get_ports { CLK12MHZ }];
set_property -dict { PACKAGE_PIN R2    IOSTANDARD SSTL135 } [get_ports { CLK100MHZ }]; #IO_L12P_T1_MRCC_34 Sch=ddr3_clk[200]
create_clock -add -name sys_clk_pin -period 10.000 -waveform {0 5.000}  [get_ports { CLK100MHZ }];

## Switches
#set_property -dict { PACKAGE_PIN H14   IOSTANDARD LVCMOS33 } [get_ports { sw[0] }]; #IO_L20N_T3_A19_15 Sch=sw[0]
#set_property -dict { PACKAGE_PIN H18   IOSTANDARD LVCMOS33 } [get_ports { sw[1] }]; #IO_L21P_T3_DQS_15 Sch=sw[1]
#set_property -dict { PACKAGE_PIN G18   IOSTANDARD LVCMOS33 } [get_ports { sw[2] }]; #IO_L21N_T3_DQS_A18_15 Sch=sw[2]
#set_property -dict { PACKAGE_PIN M5    IOSTANDARD SSTL135 } [get_ports { sw[3] }]; #IO_L6N_T0_VREF_34 Sch=sw[3]

## RGB LEDs
#set_property -dict { PACKAGE_PIN J15   IOSTANDARD LVCMOS33 } [get_ports { led0_r }]; #IO_L23N_T3_FWE_B_15 Sch=led0_r
#set_property -dict { PACKAGE_PIN G17   IOSTANDARD LVCMOS33 } [get_ports { led0_g }]; #IO_L14N_T2_SRCC_15 Sch=led0_g
#set_property -dict { PACKAGE_PIN F15   IOSTANDARD LVCMOS33 } [get_ports { led0_b }]; #IO_L13N_T2_MRCC_15 Sch=led0_b
#set_property -dict { PACKAGE_PIN E15   IOSTANDARD LVCMOS33 } [get_ports { led1_r }]; #IO_L15N_T2_DQS_ADV_B_15 Sch=led1_r
#set_property -dict { PACKAGE_PIN F18   IOSTANDARD LVCMOS33 } [get_ports { led1_g }]; #IO_L16P_T2_A28_15 Sch=led1_g
#set_property -dict { PACKAGE_PIN E14   IOSTANDARD LVCMOS33 } [get_ports { led1_b }]; #IO_L15P_T2_DQS_15 Sch=led1_b

## LEDs
set_property -dict { PACKAGE_PIN E18   IOSTANDARD LVCMOS33 } [get_ports { led[0] }]; #IO_L16N_T2_A27_15 Sch=led[2]
set_property -dict { PACKAGE_PIN F13   IOSTANDARD LVCMOS33 } [get_ports { led[1] }]; #IO_L17P_T2_A26_15 Sch=led[3]
set_property -dict { PACKAGE_PIN E13   IOSTANDARD LVCMOS33 } [get_ports { led[2] }]; #IO_L17N_T2_A25_15 Sch=led[4]
set_property -dict { PACKAGE_PIN H15   IOSTANDARD LVCMOS33 } [get_ports { led[3] }]; #IO_L18P_T2_A24_15 Sch=led[5]

## Buttons
#set_property -dict { PACKAGE_PIN G15   IOSTANDARD LVCMOS33 } [get_ports { btn[0] }]; #IO_L18N_T2_A23_15 Sch=btn[0]
#set_property -dict { PACKAGE_PIN K16   IOSTANDARD LVCMOS33 } [get_ports { btn[1] }]; #IO_L19P_T3_A22_15 Sch=btn[1]
#set_property -dict { PACKAGE_PIN J16   IOSTANDARD LVCMOS33 } [get_ports { btn[2] }]; #IO_L19N_T3_A21_VREF_15 Sch=btn[2]
#set_property -dict { PACKAGE_PIN H13   IOSTANDARD LVCMOS33 } [get_ports { btn[3] }]; #IO_L20P_T3_A20_15 Sch=btn[3]

## Pmod Header JA
#set_property -dict { PACKAGE_PIN L17   IOSTANDARD LVCMOS33 } [get_ports { ja[0] }]; #IO_L4P_T0_D04_14 Sch=ja_p[1]
#set_property -dict { PACKAGE_PIN L18   IOSTANDARD LVCMOS33 } [get_ports { ja[1] }]; #IO_L4N_T0_D05_14 Sch=ja_n[1]
#set_property -dict { PACKAGE_PIN M14   IOSTANDARD LVCMOS33 } [get_ports { ja[2] }]; #IO_L5P_T0_D06_14 Sch=ja_p[2]
#set_property -dict { PACKAGE_PIN N14   IOSTANDARD LVCMOS33 } [get_ports { ja[3] }]; #IO_L5N_T0_D07_14 Sch=ja_n[2]
#set_property -dict { PACKAGE_PIN M16   IOSTANDARD LVCMOS33 } [get_ports { ja[4] }]; #IO_L7P_T1_D09_14 Sch=ja_p[3]
#set_property -dict { PACKAGE_PIN M17   IOSTANDARD LVCMOS33 } [get_ports { ja[5] }]; #IO_L7N_T1_D10_14 Sch=ja_n[3]
#set_property -dict { PACKAGE_PIN M18   IOSTANDARD LVCMOS33 } [get_ports { ja[6] }]; #IO_L8P_T1_D11_14 Sch=ja_p[4]
#set_property -dict { PACKAGE_PIN N18   IOSTANDARD LVCMOS33 } [get_ports { ja[7] }]; #IO_L8N_T1_D12_14 Sch=ja_n[4]

## Pmod Header JB
#set_property -dict { PACKAGE_PIN P17   IOSTANDARD LVCMOS33 } [get_ports { jb[0] }]; #IO_L9P_T1_DQS_14 Sch=jb_p[1]
#set_property -dict { PACKAGE_PIN P18   IOSTANDARD LVCMOS33 } [get_ports { jb[1] }]; #IO_L9N_T1_DQS_D13_14 Sch=jb_n[1]
#set_property -dict { PACKAGE_PIN R18   IOSTANDARD LVCMOS33 } [get_ports { jb[2] }]; #IO_L10P_T1_D14_14 Sch=jb_p[2]
#set_property -dict { PACKAGE_PIN T18   IOSTANDARD LVCMOS33 } [get_ports { jb[3] }]; #IO_L10N_T1_D15_14 Sch=jb_n[2]
#set_property -dict { PACKAGE_PIN P14   IOSTANDARD LVCMOS33 } [get_ports { jb[4] }]; #IO_L11P_T1_SRCC_14 Sch=jb_p[3]
#set_property -dict { PACKAGE_PIN P15   IOSTANDARD LVCMOS33 } [get_ports { jb[5] }]; #IO_L11N_T1_SRCC_14 Sch=jb_n[3]
#set_property -dict { PACKAGE_PIN N15   IOSTANDARD LVCMOS33 } [get_ports { jb[6] }]; #IO_L12P_T1_MRCC_14 Sch=jb_p[4]
#set_property -dict { PACKAGE_PIN P16   IOSTANDARD LVCMOS33 } [get_ports { jb[7] }]; #IO_L12N_T1_MRCC_14 Sch=jb_n[4]
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

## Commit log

2026-05-24 Added pcb files
    [Qubit Control Board.kicad_pcb, Qubit Control Board.kicad_sch]
2026-06-27 Input power set up
    [Qubit Control Board.kicad_sch]
2026-06-28 Added DAC
    [Qubit Control Board.kicad_sch]
2026-06-28 Added DAC filtering
    [Qubit Control Board.kicad_sch]
2026-06-28 started on IQ mixer and added oscillator
    [Qubit Control Board.kicad_sch]
2026-06-28 VCO power input filtering
    [Qubit Control Board.kicad_sch]
2026-06-28 Finished IQ modulator with PLL/VCO
    [Qubit Control Board.kicad_sch]
2026-06-29 Enhance README with project details and structure
    Expanded project description and added details about main components, design goals, repository structure, and current status.
2026-06-29 DAC clock changed and RC filter changes
    [Qubit Control Board.kicad_sch]
2026-07-01 added RLOAD R for the DAC post filtering
    [Qubit Control Board.kicad_sch]
2026-07-02 added footprints
    [Qubit Control Board.kicad_sch]
2026-07-04 added CRC filter after the DAC
    [Qubit Control Board.kicad_sch]
2026-07-04 put in most footprints
    [Qubit Control Board.kicad_pcb, Qubit Control Board.kicad_sch]
2026-07-04 set up 6 layers for PCB
    [Qubit Control Board.kicad_pcb]
2026-07-04 did PCB layout for IQ dual 10bit data bus to DAC
    [Qubit Control Board.kicad_pcb]
2026-07-04 added decoupling caps around the DAC
    [Qubit Control Board.kicad_pcb]
2026-07-05 changed oss and updated footprint sizes on de caps
    [Qubit Control Board.kicad_pcb, Qubit Control Board.kicad_sch]
2026-07-06 Added GUI to qubit sim, also added IQ mixer feature on to the sim
    [Qubit Control Board.kicad_pcb]
2026-07-06 diff clock routing
    [Qubit Control Board.kicad_pcb, Qubit Control Board.kicad_sch]
2026-07-06 Finished diff clock routing
    [Qubit Control Board.kicad_pcb, Qubit Control Board.kicad_sch]
2026-07-07 routed USBC
    [Qubit Control Board.kicad_pcb, Qubit Control Board.kicad_sch]
2026-07-08 Add angle-pulse mode with rotation preview and fix widget cross-talk
    Adds a mode switch to the Bloch sphere GUI backed by QubitSystem.rotate_anl:
    enter a total rotation angle and axis angle, and it stage-steps the pulse
    (replaying the backend's own computed I/Q arrays) while animating the sphere
    and plotting I(t), Q(t), and amplitude(t). A live dotted preview arc shows
    how far the current state will travel before sending.
    Also fixes a real bug: Manual and Angle mode widgets share screen rects and
    were only toggled via Axes.set_visible, which doesn't gate widget event
    handling (AxesWidget.ignore only checks .active). Hidden widgets kept
    responding to clicks/drags underneath the visible ones,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
2026-07-10 updated LDO power set up
    [Qubit Control Board.kicad_sch]
2026-07-10 re did diff clock for DAC
    [Qubit Control Board.kicad_pcb, Qubit Control Board.kicad_sch]
2026-07-10 diff clock edits
    [Qubit Control Board.kicad_pcb]
2026-07-11 started on 1.8V LDO
    [Qubit Control Board.kicad_pcb, Qubit Control Board.kicad_sch]
2026-07-11 1.8V LDO
    [Qubit Control Board.kicad_pcb]
2026-07-11 board resize
    [Qubit Control Board.kicad_pcb]
2026-07-11 CRC filter routing
    [Qubit Control Board.kicad_pcb]
2026-07-11 fixed clearance issues
    [Qubit Control Board.kicad_pcb]
2026-07-11 3.3V-A LDO
    [Qubit Control Board.kicad_pcb, Qubit Control Board.kicad_sch]
2026-07-11 board resizing
    [Qubit Control Board.kicad_pcb]
2026-07-12 Added bulk caps to 3.3 and 1.8 (routing)
    [Qubit Control Board.kicad_pcb]
2026-07-17 moved decoupling caps to the bottom
    [Qubit Control Board.kicad_pcb]
2026-07-17 ERC changes
    [Qubit Control Board.kicad_sch]
2026-07-18 re doing 1.8V and 3.3V LDOs for DAC
    [Qubit Control Board.kicad_pcb, Qubit Control Board.kicad_sch]
2026-07-18 Finshed 1.8/3.3V LDO redo
    [Qubit Control Board.kicad_pcb, Qubit Control Board.kicad_sch]
2026-07-18 added 3.3V decoupling cap for DAC to the bottom
    [Qubit Control Board.kicad_pcb]
2026-07-18 added extra F beads to PLL power input
    [Qubit Control Board.kicad_pcb, Qubit Control Board.kicad_sch]
2026-07-19 LF edits and cap resizing
    [Qubit Control Board.kicad_pcb, Qubit Control Board.kicad_sch]
2026-07-19 LF routing + power routing for PLL
    [Qubit Control Board.kicad_pcb]
2026-07-19 Did 3.3V-B LDO routing
    [Qubit Control Board.kicad_pcb, Qubit Control Board.kicad_sch]
2026-07-19 SPI control and power routing
    [Qubit Control Board.kicad_pcb]
2026-07-19 Added 10n input caps to PLL power rails
    [Qubit Control Board.kicad_pcb, Qubit Control Board.kicad_sch]
2026-07-19 added series R to FB to add damping to oss
    [Qubit Control Board.kicad_pcb, Qubit Control Board.kicad_sch]
2026-07-19 REREF routing with on board clock
    [Qubit Control Board.kicad_pcb, Qubit Control Board.kicad_sch]
2026-07-19 RFOUT routing + SMA
    [Qubit Control Board.kicad_pcb]
2026-07-19 SPI routing
    [Qubit Control Board.kicad_pcb]
2026-07-19 5V pour
    [Qubit Control Board.kicad_pcb]
2026-07-20 DRC stuff
    [Qubit Control Board.kicad_pcb]
2026-07-20 DRC changes
    [Qubit Control Board.kicad_pcb]
2026-07-20 PLL GND pad vias
    [Qubit Control Board.kicad_pcb]
2026-07-20 Made BOM
    [Qubit Control Board.csv, Qubit Control Board.kicad_pcb, Qubit Control Board.kicad_sch]
2026-07-22 RFOUT Z tuning
    [Qubit Control Board.kicad_pcb]
2026-07-22 Stitching on RFOUT
    [Qubit Control Board.kicad_pcb]
2026-07-22 Ground pour around loop filter added
    [Qubit Control Board.kicad_pcb]
2026-07-23 DAC output Z ctrl
    [Qubit Control Board.kicad_pcb]
2026-07-23 DAC clock Z ctrl
    [Qubit Control Board.kicad_pcb]
